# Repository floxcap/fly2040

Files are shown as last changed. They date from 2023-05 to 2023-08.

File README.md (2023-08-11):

# fly2040

RP2040 board, leds, firmware and homebrew designed to be picofly compatable.

NOTE: Using `git-subrepo` for submodules. See [git-subrepo](https://github.com/ingydotnet/git-subrepo) for usage.

## Credits
- Further credits in relevant sub-folders.
- A huge thank you to [SciresM](https://github.com/SciresM) for all of the guidance and help in getting this working.
- Also a huge thank you to [CTCaer](https://github.com/CTCaer) for all of the guidance and focus on the small details.
- Thanks to [rehius](https://github.com/rehius) for the picofly firmware which was the foundation for the fly2040 firmware.
- Thanks to [lightninjay](https://gbatemp.net/members/lightninjay.643395/) for his guide [guide](doc/PicoFlyGuideV.6.2-1.pdf) and [guide-thread](https://gbatemp.net/download/a-definitive-picofly-install-guide.37968/).

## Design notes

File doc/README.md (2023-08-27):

# fly2040

RP2040 board is intended to be connected to I2C port #1.

The V1_V2 image shows the points I used for my mod.
The Lite image shows the likely points for a Lite board - but has not yet been confirmed or tested.

You may be able to trace the board layers/i2c points using: [Board Layers](https://balika011.hu/switch/)

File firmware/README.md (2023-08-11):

# fly2040 firmware

Firmware derrived from picofly firmware.

Added i2c slave mode for WS2812 led strip control from homebrew.

For i2c to work with the sysmodule as it it will need to be connected to i2c bus #1.

(Images to be inserted here)

## Credits
- Thanks to [rehius](https://github.com/rehius) for [usk](https://github.com/rehius/usk)
- Thanks to [vmilea](https://github.com/vmilea) for [pico_i2c_slave](https://github.com/vmilea/pico_i2c_slave)

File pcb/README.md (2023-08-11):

# fly2040 pcbs
KiCad designs for a RP2040 board and supporting boards.

Note - The main board requires a 3.3V power supply when programming.<br>
The intention is to be able to program the boards with a 1.27mm pitch test clip / pogo pins.
(See: [usb_programmer](usb_programmer)).

The [fly2040_rgb](fly2040_rgb) board is the main board and has been tested and working
on V1/V2/Lite devices.

The [fly2040_leds](fly2040_leds) adds support for a flex led strip.

The [cpu_flex](cpu_flex) is untested.

## Installation
See: [guide](../doc/PicoFlyGuideV.6.2-1.pdf) or [guide-thread](https://gbatemp.net/download/a-definitive-picofly-install-guide.37968/)

The usb-programmer board is designed to accept the P50-E2 (shaft diameter 0.68mm) which should be soldered in
to the (programmer) board.
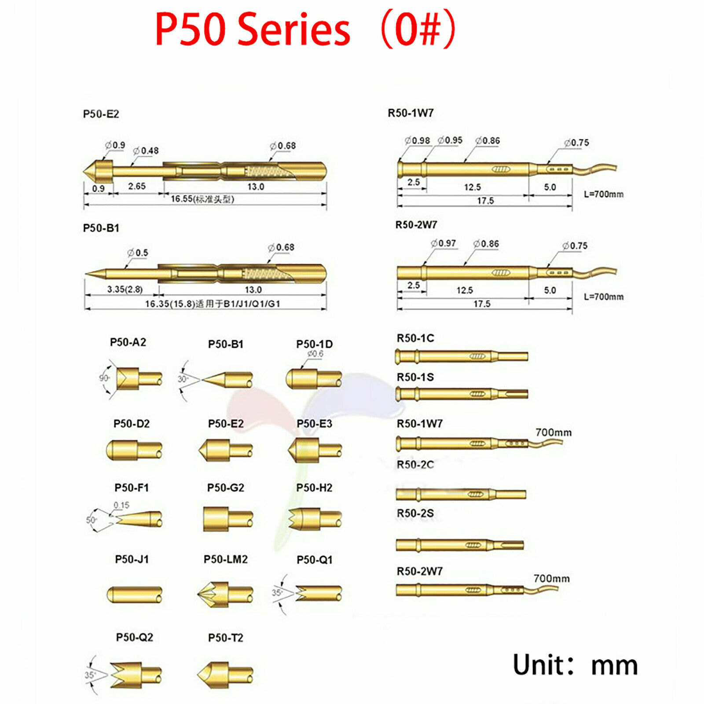
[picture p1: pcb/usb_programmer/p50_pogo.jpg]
Pogo pins


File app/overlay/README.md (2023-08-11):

# sys-rgb overlay

overlay is not currently developed.
TBD / TODO.

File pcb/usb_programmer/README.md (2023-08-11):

# fly2040 USB Programmer
KiCad design for a basic programmer board.

Note - This design is currently untested.

The usb-programmer board is designed to accept the P50-E2 (shaft diameter 0.68mm) which should be soldered in
to the (programmer) board.<br><br>


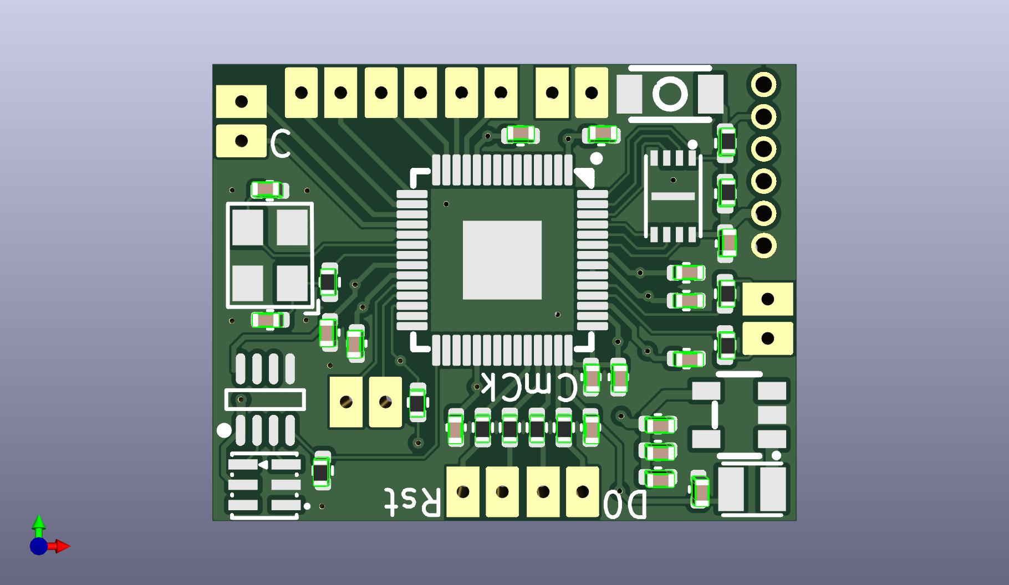
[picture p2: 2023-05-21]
images/fly2040_front.jpg

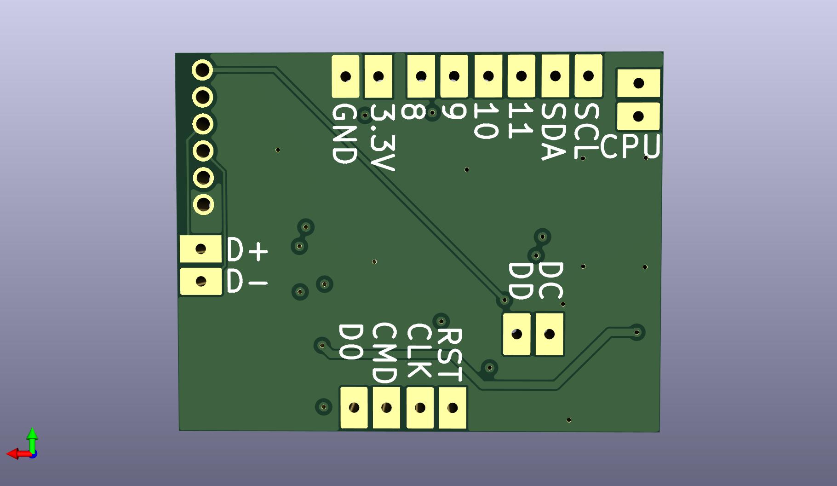
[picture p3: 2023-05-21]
images/fly2040_back.jpg

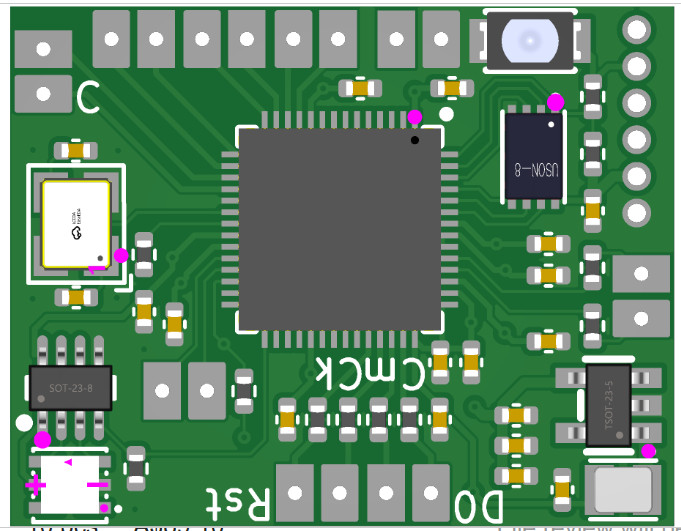
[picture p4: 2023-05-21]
images/jlcpcb.jpg

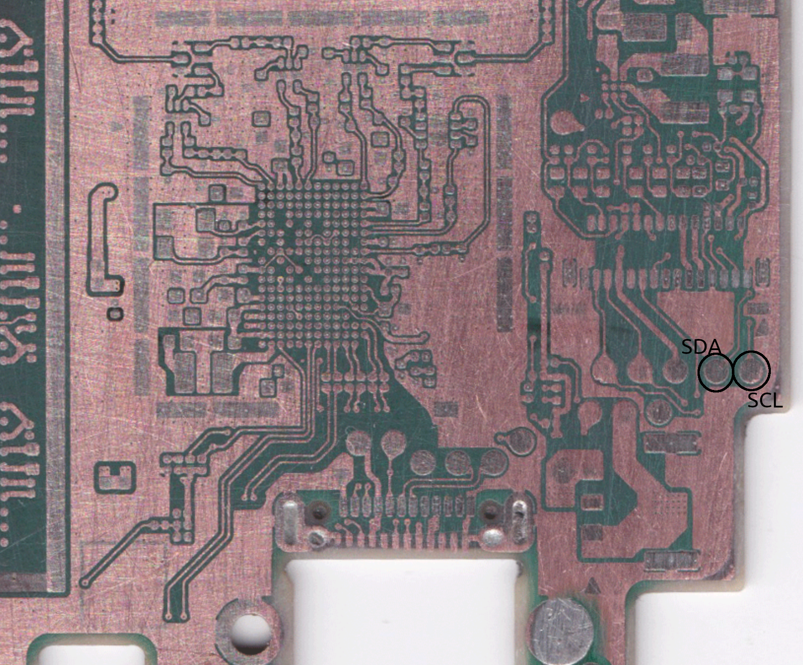
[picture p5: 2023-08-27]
doc/Lite_i2c_1_unconfirmed.png

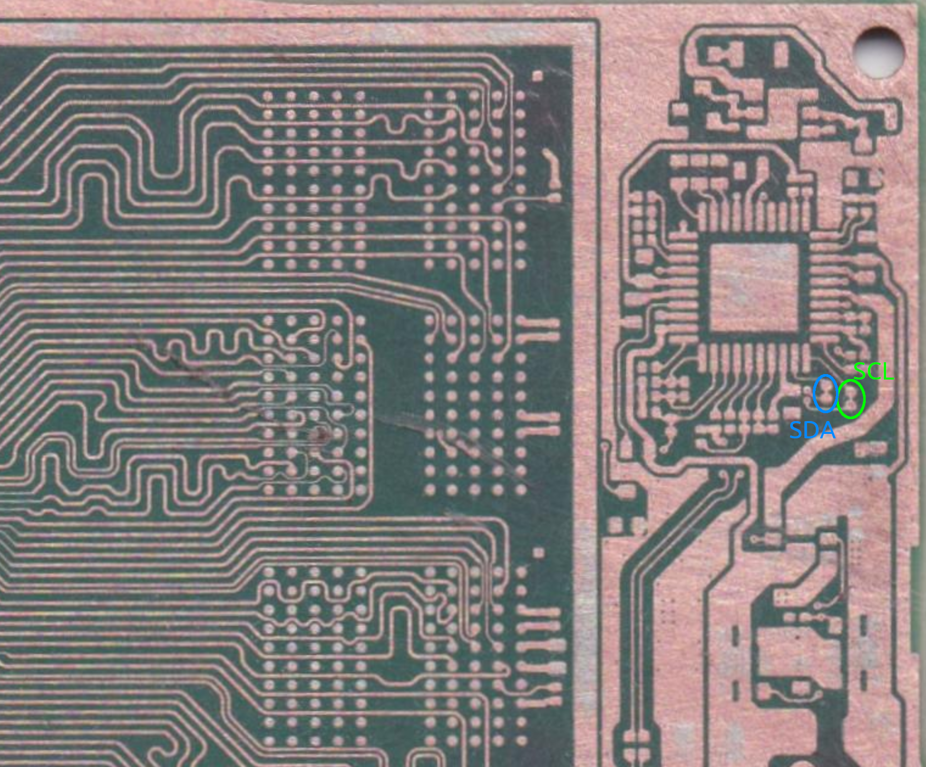
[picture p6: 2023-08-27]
doc/V1V2_i2c_1.png

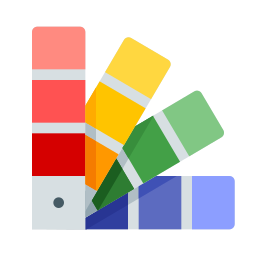
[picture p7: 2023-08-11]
app/manager/resources/img/sys-rgb.png

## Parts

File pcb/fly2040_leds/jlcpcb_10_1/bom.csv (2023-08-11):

Comment | Designator | Footprint | LCSC
XL-1010RGBC-WS2812B | U1,U2,U3,U4,U5,U6,U7,U8,U9 | kicad_lceda:LED-SMD_4P-L1.0-W1.0-TL_XL-1010RGBC-WS2812B | C5349953

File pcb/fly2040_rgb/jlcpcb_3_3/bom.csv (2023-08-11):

Comment | Designator | Footprint | LCSC
47 | R9,R10,R11 | R_0402_1005Metric | C25118
100nF,16V,X7R | C2,C4,C7,C8,C9,C10,C11,C12,C13,C14 | C_0402_1005Metric | C1525
10k | R2,R3,R4,R6,R7,R12 | R_0402_1005Metric | C25744
RP2040 | U1 | kicad_lceda:LQFN-56_L7.0-W7.0-P0.4-EP | C2040
1k | R1,R5 | R_0402_1005Metric | C11702
EVPAWED40 | SW1 | kicad_lceda:KEY-SMD_L3.0-W2.0-LS3.5 | C2858607
W25Q16JVUXIQ | U2 | kicad_lceda:USON-8_L3.0-W2.0-P0.50-BL-EP | C2843335
XL-1010RGBC-WS2812B | U5 | kicad_lceda:LED-SMD_4P-L1.0-W1.0-TL_XL-1010RGBC-WS2812B | C5349953
27pF,50V,C0G | C1,C3 | C_0402_1005Metric | C1557
SMD-3225_4P_12.000MHZ_9PF | X1 | kicad_lceda:OSC-SMD_4P-L3.2-W2.5-BL | C362368
1uF,25V,X5R | C5,C6 | C_0402_1005Metric | C52923

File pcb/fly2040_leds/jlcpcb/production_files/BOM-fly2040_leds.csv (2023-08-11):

Comment | Designator | Footprint | LCSC
XL-1010RGBC-WS2812B | U1,U2,U3,U4,U5,U6,U7,U8,U9 | LED-SMD_4P-L1.0-W1.0-TL_XL-1010RGBC-WS2812B | C5349953

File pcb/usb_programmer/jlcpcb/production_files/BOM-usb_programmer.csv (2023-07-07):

Comment | Designator | Footprint | LCSC
TYPE-C-31-M-12 | J1 | USB_TYPE-C | C165948
10k | R1 | R_0402_1005Metric | C25744
5.1k | R2,R3 | R_0402_1005Metric | C25905
KMR221GLFS | SW1,SW3 | KEY-SMD_KMR2XXGXXX | C72443
RT9080-33GJ5 | U1 | TSOT-23-5_L2.9-W1.6-P0.95-LS2.8-BL | C841192

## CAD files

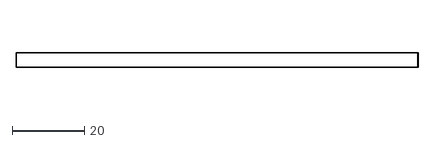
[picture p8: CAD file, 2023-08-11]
pcb/fly2040_leds/Gerber/fly2040_leds-User_Comments.dxf
111.2 x 4.05

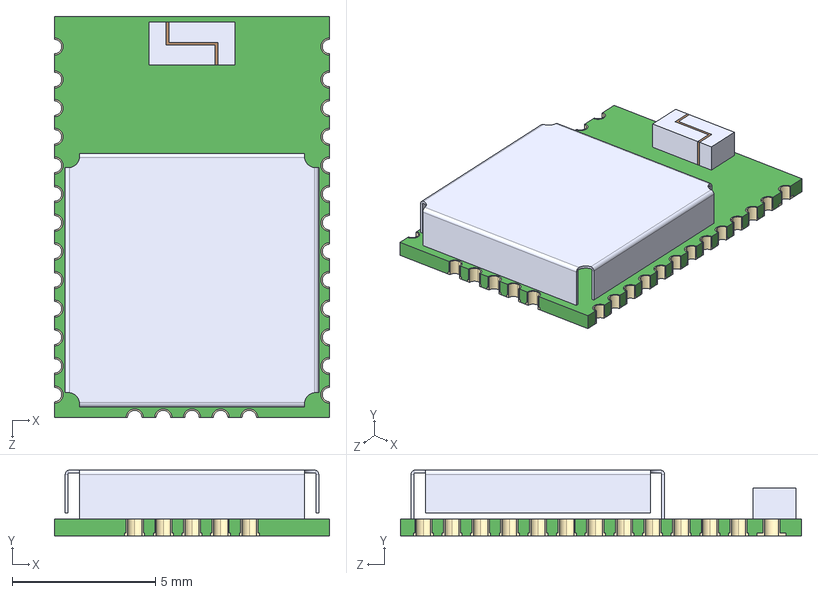
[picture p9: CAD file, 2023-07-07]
pcb/usb_programmer/3DSteps/CAM-M8Q-0.step
9.60 x 2.30 x 14.0 mm

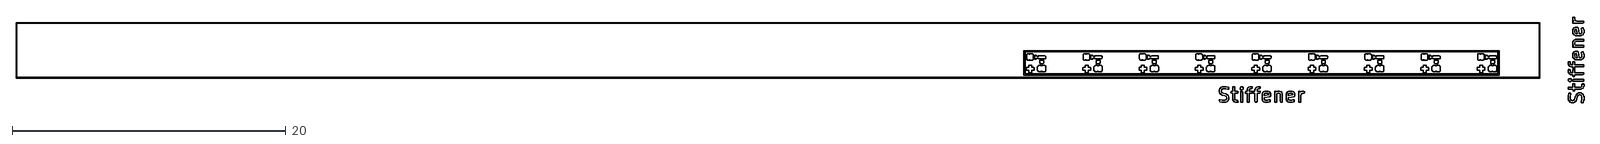
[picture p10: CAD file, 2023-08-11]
pcb/fly2040_leds/Gerber/fly2040_leds-User_Drawings.dxf
114.5 x 6.24

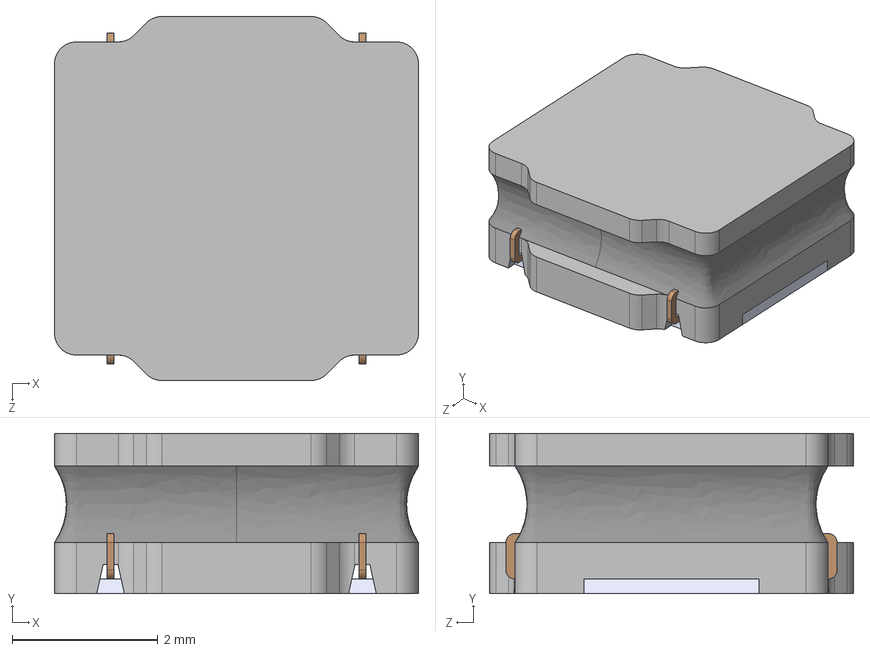
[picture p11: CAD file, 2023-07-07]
pcb/usb_programmer/3DSteps/IND_LQH5BPN4R7NT0L.step
5.00 x 2.20 x 5.00 mm

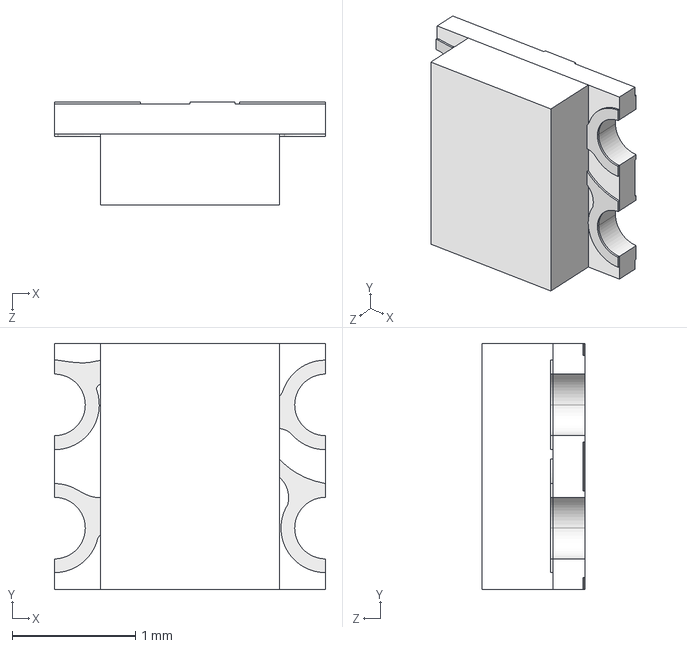
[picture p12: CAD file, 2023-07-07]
pcb/usb_programmer/3DSteps/WS2812-2020.step
2.20 x 2.00 x 0.84 mm

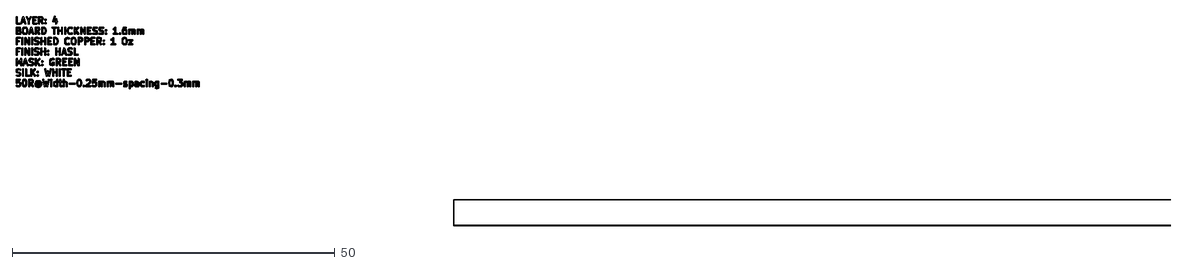
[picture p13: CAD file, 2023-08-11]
pcb/fly2040_leds/Gerber/fly2040_leds-Margin.dxf
179.1 x 32.5

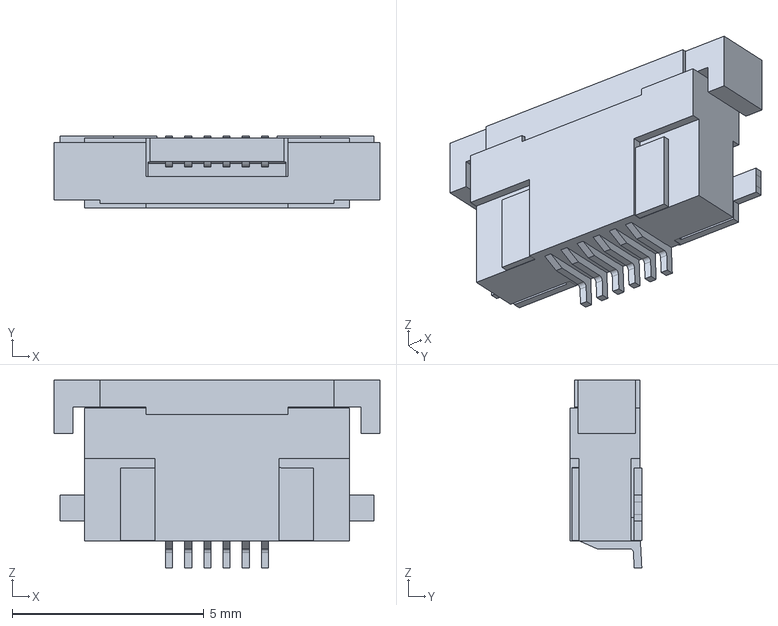
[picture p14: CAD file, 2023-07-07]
pcb/usb_programmer/3DSteps/FPC_6PIN_sfv6r3ste1hlf.stp
8.50 x 1.87 x 4.90 mm

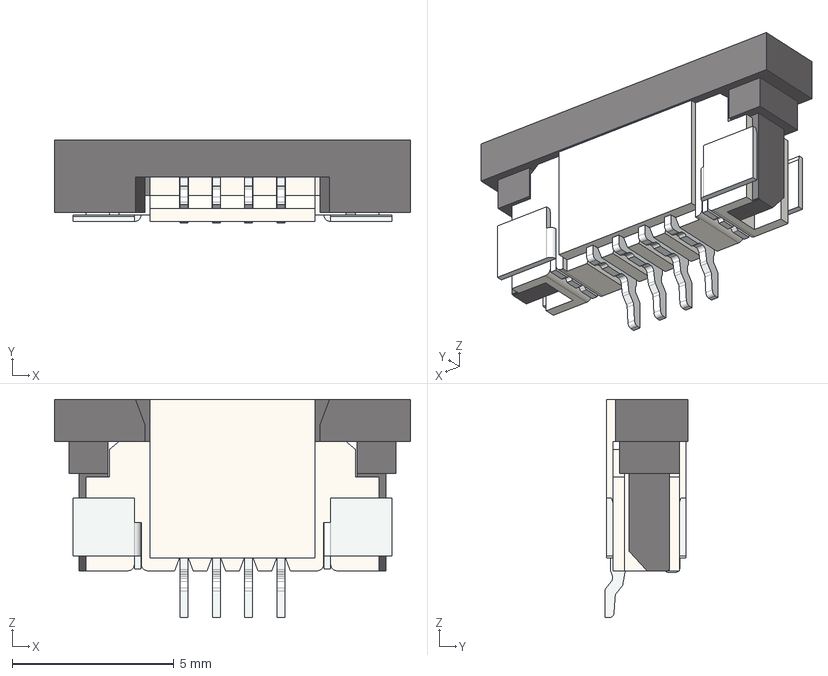
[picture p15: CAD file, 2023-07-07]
pcb/usb_programmer/3DSteps/FFC3B07-04-T.stp
11.0 x 2.57 x 6.75 mm
_FFC3B07-04_H1
_FFC3B07-04_H2
_FFC3B07_SC x 2
_FFC3B07-T_P x 4

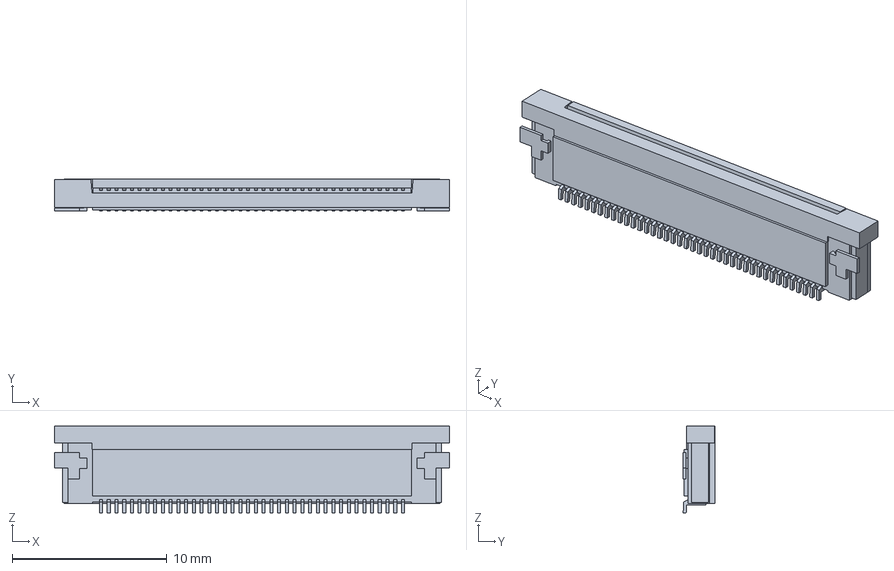
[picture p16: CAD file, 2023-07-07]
pcb/usb_programmer/3DSteps/TFT_62684402100alf.stp
25.5 x 2.05 x 5.60 mm

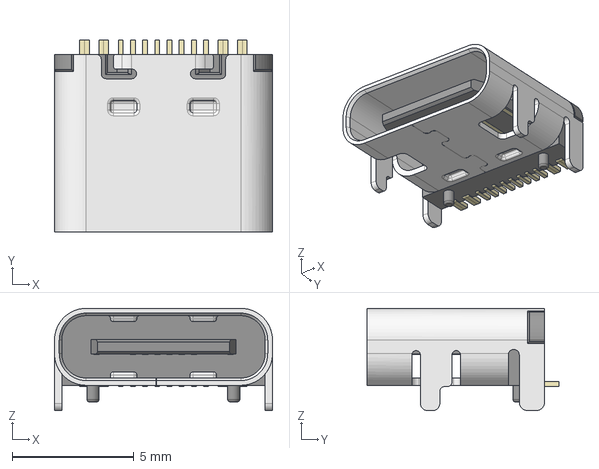
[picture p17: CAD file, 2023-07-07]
pcb/usb_programmer/3DSteps/HRO_TYPE-C-31-M-12.step
8.95 x 7.90 x 4.20 mm

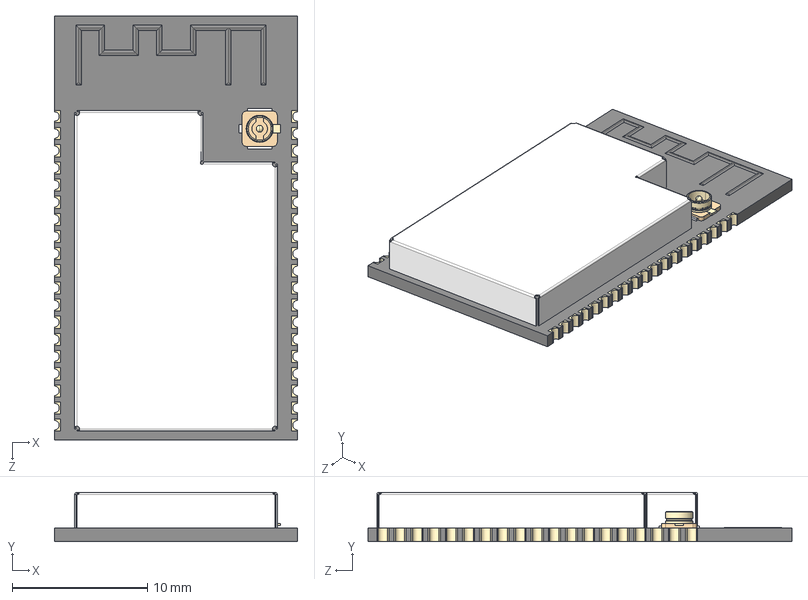
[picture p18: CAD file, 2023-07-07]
pcb/usb_programmer/3DSteps/ESP32-WROVER-E.step
18.0 x 3.65 x 31.4 mm

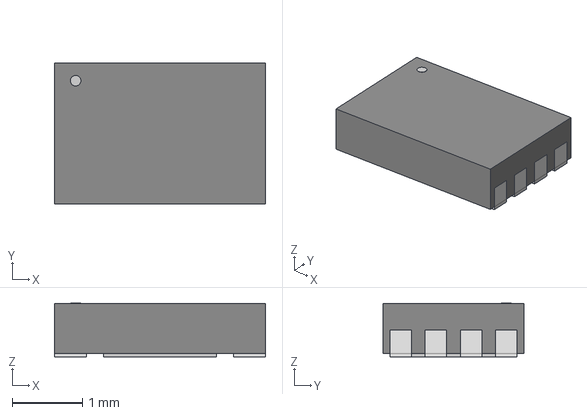
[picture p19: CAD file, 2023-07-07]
pcb/usb_programmer/3DSteps/TDFN8_2x3MC_MCH.step
3.00 x 2.01 x 0.765 mm

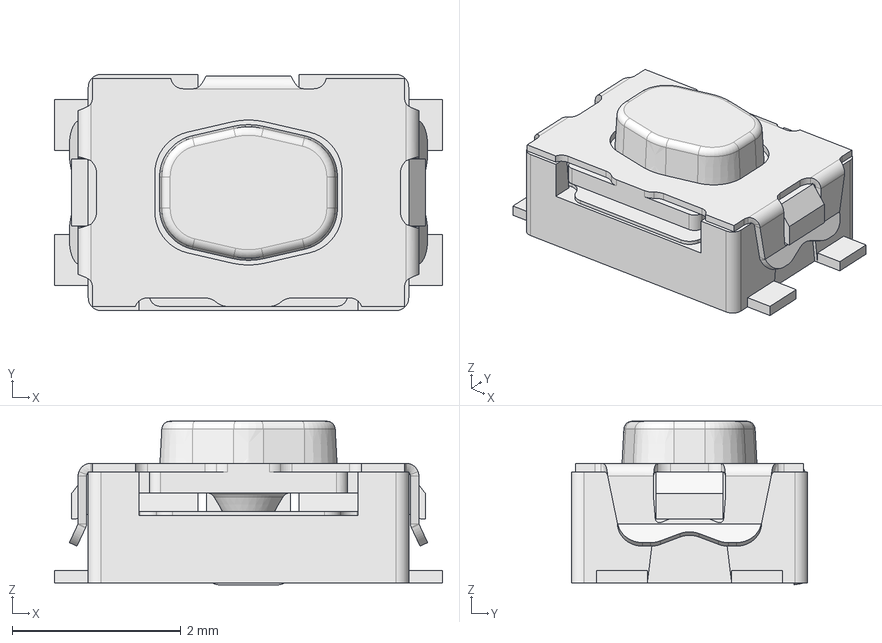
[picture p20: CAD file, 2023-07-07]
pcb/usb_programmer/3DSteps/KMR211GLFS.step
4.60 x 2.80 x 1.94 mm

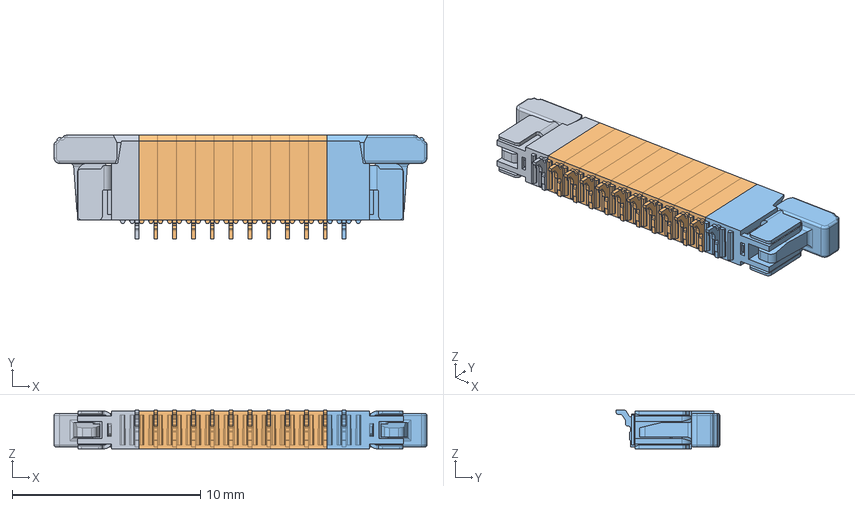
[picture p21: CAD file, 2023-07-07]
pcb/usb_programmer/3DSteps/F52R-1A7H1-11012.stp
19.8 x 5.50 x 2.05 mm
F52R_L
F52R_M x 10
F52R_R

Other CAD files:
pcb/usb_programmer/3DSteps/2-84952-4.step
pcb/usb_programmer/3DSteps/S2B-PH-SM4-TB(LF)(SN)--3DModel-STEP-56544.STEP
pcb/usb_programmer/3DSteps/KMR621NG LFS.step
pcb/usb_programmer/3DSteps/436333045822_Download_STP_436333045822_rev1.stp
pcb/usb_programmer/3DSteps/528080470.stp
pcb/usb_programmer/3DSteps/WLCSP6_1P48X0P98_ONS.step

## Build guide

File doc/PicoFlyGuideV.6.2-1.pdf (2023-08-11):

Flashing your PicoFly, An Overview
At the heart of all the dev boards is an SoC (System on a Chip) known as the RP2040. It has its own built-in firmware flashing system that involves it presenting itself to your computer as a USB drive.
If it has never been programmed before, simply plugging it into your computer should bring up a window with two files in it. This is the firmware flashing window. If you drag and drop a ".uf2" file into this window, the RP2040 will read the file and attempt to flash it. This will cause the window to close, and the next time you plug the RP2040 in, it will not present itself as a USB drive to your PC.
To reprogram an already-programmed RP2040, there is typically a "boot" button that needs to be held down while being plugged into USB, but when you do this and the window shows up, your firmware file will not be displayed in the window since it IS NOT a storage device. The RP2040 just tricks your computer into treating it like a storage device. Some recommend that between flashes you use a "flash_nuke.uf2" provided by the Raspberry Pi Foundation. This basically just flashes all zeroes to the RP2040 firmware memory to ensure a clean flash of whatever you put on it next.

We want to flash our device with Rehius' most up-to-date PicoFly firmware, which can be located at GBAtemp:

https://gbatemp.net/threads/picofly-a-hwfly-switch-modchip.622701/page-78#post-10090767

As of the current date (4-06-2023), "fw_2.74.uf2" is what needs to be flashed to your dev board. Remove the .pdf from the end of the file before flashing.

With this file downloaded, and your RP2040-Zero plugged into your PC, showing the firmware flashing window, keep one eye on the LED of your RP2040-Zero. As you drop the .uf2 file into the window, your LED should flash as the window on your PC closes. This is to indicate firmware flashing success, but the color of this LED is what we are concerned with now.

If the LED flashes Yellow once, GREAT, you don't need to do anything special, however, if you get multiple flashes, or no flash at all, the flash was unsuccessful and you need to attempt flashing the firmware once again.

You can hold the boot button, plug your RP2040-Zero back into your computer, flash the .uf2 to the board again and look for a Yellow LED flash now.

At this point, with a firmware loaded on the board, we can start to prep it to go into the switch.

Conventionally, folks remove the USB-C port and the boot + reset buttons. Below is an example of a finished install with USB-C removed, buttons removed, resistors installed, and as you may notice, a mix of 30awg Kynar (for power supply to RP2040-Zero) and about 36awg magnet wire for the remaining wires.

During this step of removing ports, it is also recommended to add the three resistors to the side of your board. With the boot button removed, some people place their resistors to the inside of the board, rather than hanging from the edge. Both will functionally work.

If you have slow EMMC issues after putting everything together, one possible reason is that you need two additional resistors, one each on CMD and DAT0, like below, for a total of 94 ohms on each line:

There could be other reasons for slow EMMC as well though, like residual flux on solder points, or wires being too thin or too long on CLK, CMD, or DAT0.

On that same note, if you leave flux residue on RST points, your console could instantly reboot after startup, as the RST points are very sensitive.

Time to open up your console and get to work!

# Preparing your PicoFly

1) Nintendo Switch (V1, V2, Lite, or OLED) ANY model
2) Soldering station
- Soldering iron that is preferably digitally controlled so you know what temp you solder at
- Solder (some recommend low-temp leaded fluxless solder to make some parts slightly easier)
- Flux (this is NOT optional. When soldering at these scales, flux is absolutely vital to making good solder joints) Applied with the tip of a wooden toothpick is how I usually hit small spots
- A damp sponge and/or brass wire sponge to keep your soldering tip clean. I use both.
- The tip you use can be vital depending on the locations of your soldering points. I use a ts-100 iron and swap between three different tips:
TS100-JL02 | TS-BC2

TS-I

3) A tweezer kit
I know this sounds ridiculous, but trust me. Handling components this small REQUIRES fine-point tweezers. You may be able to SEE the components without a magnifier or scope, but you won't be able to manipulate and solder things like 0805 (or even smaller) resistors with bare fingers.

I ordered this kit off of Amazon https://www.amazon.com/gp/product/B07S1DMKDX/

4) Wire
This would seem like a no-brainer, but the type of wire you use can ultimately make or break your install. I used a mix of 30awg Kynar and 40awg magnet wire. I have seen installs with all 30awg, and installs with all 40awg. Your luck may vary, but smaller wire tends to be a little more forgiving on small components when soldering.
5) 47ohm to 50ohm 0805 Resistors These resistors are soldered onto DAT0, CLK, and CMD on the PicoFly, then wires are soldered from the switch motherboard to the resistors. There are two types you can generally get away with using: 470 and 47R0 The 470 typing are 47 ohms +/-5% whereas 47R0 are 47 ohms +/-1%
Other sizes than 0805 will work, but 0805 seem to be easier to fit on the soldering pads of the RP2040-Zero
6) Mosfet(s) or an HWFLY flex cable appropriate to your specific console.
-If using mosfets by themselves, it is recommended that you purchase model IRFHS8342 due to its size and its ability to fit in place under the APU shield

-If using a flex cable (which has integrated mosfets) then order a V1 cable for Erista models, or a V2 cable for Mariko, Lite, or OLED models (You can also use V3 OLED cables, it's a choice of where the flex cable comes out of the APU shield).

Erista | Mariko/Lite/OLED
7) A magnifier of some kind
There are plenty of folks (myself included) that can get away with using a cellphone camera to zoom in and make sure joints aren't bridged and that good solder contact is being made. Others will say you absolutely need a scope to do this job so that you can see all the small components on a well-lit screen while working. It's up to what you're most comfortable with.
8) Kapton Tape
This seems to get overlooked in some cases, but the kapton tape helps to electrically isolate the picofly from accidentally shorting anything once it's installed and closed up.
9) Thermal Paste
Another oft-overlooked item to improve your switch's lifespan after this mod. Good thermal paste being properly applied after cleaning all the old stuff off is vital to not overheating your console which leads to console shutoff into standby mode.

Last but not least
10) An RP2040 dev board
This is partially where the community starts to get divided, beyond what kind of switch you are modding.
A vast majority of the community has been using RP2040-Zero boards from Waveshare/Aliexpress, but thanks to Rehius, the firmware dev, several types of dev board are currently supported. I will attempt to list some of the most popularly used ones thus far. For this guide, I am focusing on The RP2040-Zero
~ RP2040-Zero ~ RP2040-One ~ RP2040-Tiny

~ Seeed XIAO-RP2040 ~ Adafruit ItsyBitsy RP2040

See the end of the guide for diagrams of how to wire up the Seeed or the Adafruit

Optional, but recommended
11) UV-cure solder mask
-It cannot be overstated how small these components are. Once your wires are faithfully
in place, many would recommend a small amount of solder mask be applied to hold things in place,
as well as help insulate connections from shorting
12) Digital Multimeter
-Use this to check your wiring when you are done. It can be used to detect shorts to ground, or in diode mode to detect proper connections. If you don't understand any of that, THIS MOD IS NOT FOR YOU, HAVE A PROFESSIONAL INSTALL IT FOR YOU.

Recommended materials

Here there be DRAGONS! DOING THIS MODIFICATION TO YOUR SWITCH MAY CAUSE PERMANENT DAMAGE. I RECOMMEND YOU HAVE THIS DONE BY A PROFESSIONAL INSTALLER.

"Just because a mod is cheap doesn't mean it's easy. -Trust me I learnt the hard way" - Adran (GBATEMP 2023)

SERIOUSLY, if you've NEVER soldered before, this is not the mod for you to attempt yourself. The photos that you've seen to make you so confident you can do this yourself? They're usually in the ballpark of 10-20 times zoom. Most of the things you are seeing on this scale are millimeter or smaller in measurement. This mod requires good lighting, steady hands, all the right equipment, and most of all, experience with soldering. Knowledge of why flux works, and why it is so important to be used in small projects like this cannot be overstated. Please, don't kill your switch, this isn't r/techgore, we don't want to see photos of your ripped traces and your tears stained on the motherboard...

Disclaimer: this guide is written using many different sources of information. It is not my work, I am merely combining it here in this PDF to make it more accessible to the general public. I take no responsibility for anything that may happen to your device, good or otherwise. This guide is provided as-is, and you are responsible for anything that may happen.

This guide will go over the basics of PicoFly setup, and wants to reiterate, this hardware mod can be installed on ANY switch (including unpatched V1's) running ANY firmware. It is CPU-glitch based, which loads a payload before Nintendo-signed software bootloader.

V.6.2

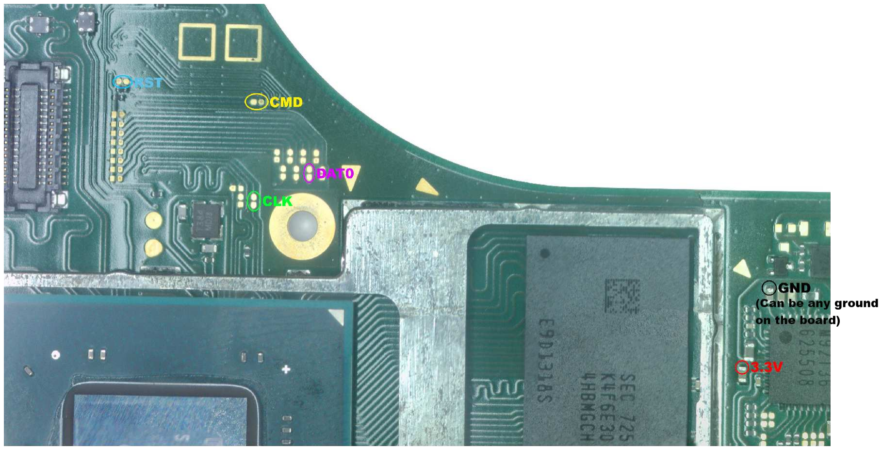
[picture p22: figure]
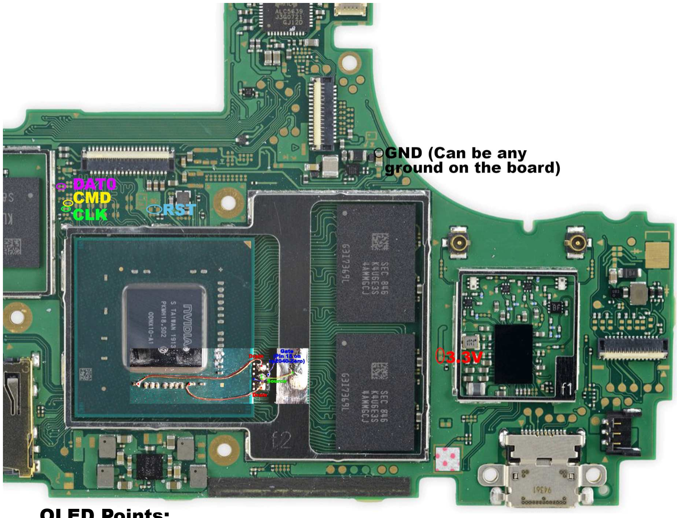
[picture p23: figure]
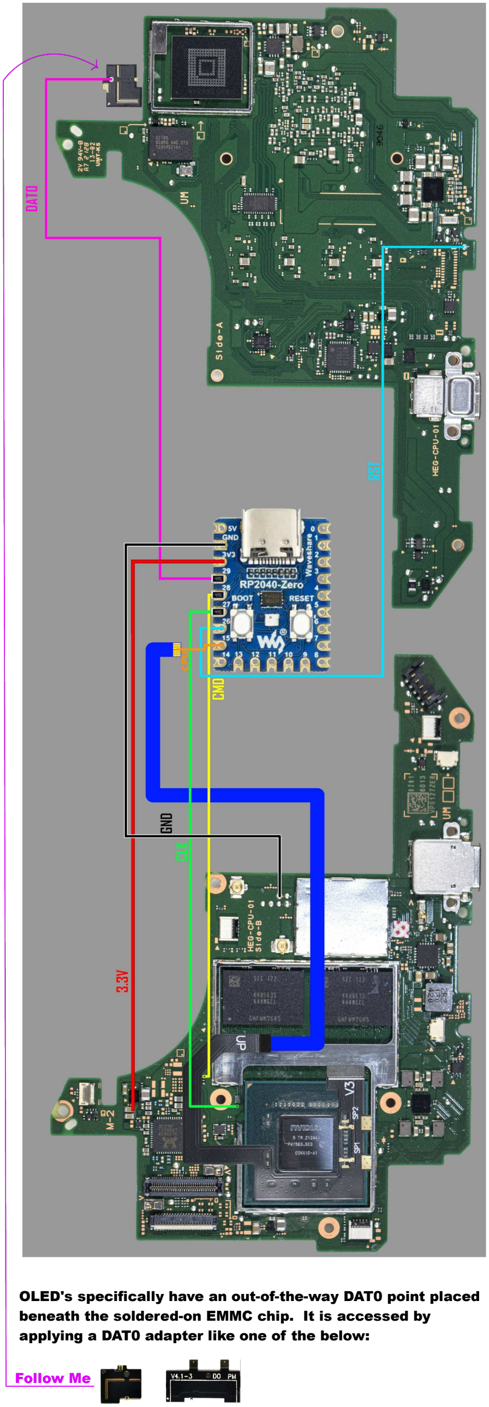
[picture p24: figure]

Bear in mind, I recreated these images in photo editing software, but this is what is currently displayed on my switch. I have flashed several updates, so my fuse count is greater than 0, and I am currently on v2.64

Updating
To actually use the tool to update your picofly from V2.6+ to something higher, simply place the desired firmware's ".bin" update in the root of your SD card and name it "update.bin". Launch PicoFly Toolbox, then scroll down once to "Update" by hitting "Vol -" one time, then hit the power button once. The toolbox will now look for the "update.bin" where it is supposed to be, and will flash the firmware provided inside the file. You will be asked to reboot, and may experience slightly longer boot times for the first few boots after updating. This is normal, once the PicoFly re-trains, you will be back to fast boots.

Rolling Back
PicoFly stores the last firmware you flashed from, in the event of a failed flash, it can auto-rollback to whatever version you were flashing from. If in the event you have a successful flash to a higher version, but wish to intentionally rollback to your previously running version, from the main menu of PicoFly Toolbox, scroll down twice with the Vol - button being pressed twice, then select Rollback with the power button. Similar to an update, you will be asked to reboot.

SD Loader
To my understanding, SD Loader is the portion of Boot0 which is being modified to load unsigned SD payloads (such as our custom bootloader of choice, typically Hekate). The "No SD Card" screen is part of this SD Loader portion. To make a backup or restore this portion, just use the two options seen in their respective portion of the menu, but you really shouldn't have to mess with this unless directed to do so.

Training Data Reset
As the name might imply, this is to reset the training data of the PicoFly in the event your boot times have gone awry for some reason. This will clear your training data and allow your PicoFly to attempt relearning new glitch timings for your console. Largely this should be unnecessary, but it is here if needed.

This guide has been brought to you by Lightninjay, a member of the GBATEMP forums, and in no way implicates them for any harm that may come to you or your devices while following this guide.

As a courtesy, here are some pinouts of alternate boards that PicoFly should be compatible with, thanks to forum member, Dee87, colors added by myself

SEEED XIAO-RP2040

Adafruit ItsyBitsy RP2040

Raspberry Pi Pico

There are plenty of guides on Youtube on how to properly open your console, so I will merely reference those below:

V1 and V2 disassembly:
https://www.youtube.com/watch?v=QCZ3-fYjpWo

Lite disassembly:
https://www.youtube.com/watch?v=GP1DHRs6V2Y

OLED disassembly:
https://youtu.be/4umniX8nX5E?t=40s

Once you're inside, you'll need to reference the following photos to solder your wires into the console:

Please Be Advised:
You may see two pads inside one circle in the below photos. THIS IS INTENTIONAL. This means that both pads are part of the same trace. That means you can solder to either pad, or both, whichever suits the size of wire you are using.

If using a flex cable, the CPU pin on your RP2040 needs to be connected to the two middle pins of the flex cable (pins

### 3 and 4). Do not bridge to pins 2 or 5 accidentally, this will

likely cause an error light on your RP2040. Use Kapton tape as seen below to make soldering the two pins easier:

V1/V2 Points:

Lite Points:

OLED Points:

OLED's specifically have an out-of-the-way DAT0 point placed beneath the soldered-on EMMC chip. It is accessed by applying a DAT0 adapter like one of the below:

Use this link to watch sthetix place his adapter and wire it up: https://youtu.be/y5-TPVecVsw?t=415

The last part is the installation of mosfets or of the HWFLY cable. Functionally the install is the same for all models, the main difference is orientation of the vertical APU capacitors from the V1 model to the other 3 models that place the capacitors horizontally. Here is a section of a video with one of these cables being installed:

https://youtu.be/XG80TcbO5Uo?t=107

If you do not have access to a cable and are doing a bare mosfet install, here are some photos to reference
of the clever ways people have been wiring theirs up:
- V1 Erista (vertical capacitors)

-V2 Mariko, Lite, OLED

If it isn't so clear, here are a few photos of some mosfet installs:

This is a single mosfet install, where the left capacitor of this V2 board has been removed, so the wire is just hitting the right-side pad of the left cap:

And here is a slightly more complex, but well-executed, install of double mosfets that have been secured with solder-mask:

Also importantly, if you are to accidentally remove one or more of these capacitors, you may be fine, but to replace them, you can rob a few off of a RP2040-Zero, without affecting the function of the PicoFly. These 100nF caps are located here:

Once you have your mosfet(s) installed, make sure all your new points are electrically insulated from the APU shield as you put it back on.

Now simply solder all of your flying wire leads to their appropriate points on your RP2040.

Before attempting to boot, make sure you did not accidentally bridge any extra contacts, as this could ruin your console.

Once you're ready, push the power button on your console after plugging the battery back in. The PicoFly should flash blue, (on first boot, it should flash white after blue) then yellow to indicate success! Should you see this order of lights, try flipping your console over carefully and checking the screen to see this

If you're met with this screen, then that is as far as this guide takes you, as you have successfully modded your switch with PicoFly, congratulations! At this point you can follow any number of HATS pack guides to prepare an SD card for your device, but the gist is that it is looking for a "payload.bin" located in the root of the SD card. As long as all the supporting files for that payload.bin have been copied to the SD card along with it, then everything should boot fine.

On the other hand, if you didn't see Blue, White (SDloader Mem write), then Yellow on your LED, and your console either boots to a black screen, or instead boots to OFW like normal, then look at the following LED code list to diagnose your potential issue:
= is long Yellow pulse, * is short Yellow pulse:

= USB flashing done, * Successful glitch

** RST is not connected
*= CMD is not connected
=* D0 is not connected
== CLK is not connected

*** No eMMC CMD1 responce (bad eMMC?)
**= No eMMC block 1 read (should not happen)
*=* No eMMC block 0 read (eMMC init failure?)
*== No eMMC CMD1 request (poor wiring, or dead CPU)

=** eMMC init failure during glitch process
=*= CPU never reach BCT check, should not happen
==* CPU always reach BCT check (no glitch reaction, check mosfet)
=== Glitch attempt limit reached, cannot glitch

=*** eMMC init failure
=**= eMMC write failure - comparison failed =*=* eMMC write failure - write failed
=*== eMMC test failure - read failed
==** eMMC read failed during firmware update ==*= BCT copy failed - write failure
===* BCT copy failed - comparison failure
==== BCT copy failed - read failure

Hopefully at this point you have managed to hack your console, and are looking forward to the following hours of configuring and tweaking your setup! If not, and you're still having glitch issues and are on firmware 2.70 or higher, you can try installing two additional i2c wires for a low-voltage glitch:
From Rehius:
If your glitch is unstable (==* error), and
the proper boot happens only when you press Reset after joycon logo, you can add two more wires to make glitch much better.
board pins:
Waveshare rp2040: SDA=12, SCL=13
Pi Pico: SDA = 19, SCL = 20
XIAO 2040: SDA=3, SCL=4
ItsyBitsy 2040: SDA = 18, SCL = 19
V1/V2 | Lite

OLED

## PicoFly Toolbox

"picofly_toolbox_0.2.bin" (available from Rehius' post where the firmware is downloaded from) is the current payload that you can load through Hekate's payload launcher, to interface with your PicoFly. The caveat to this, is that you must be on at least firmware v2.6 to use the toolbox as a feature. This means, if you have previously loaded your PicoFly with an out-of-date firmware, like the frequently circulated "2.5 toshiba + unlock", you must flash at least 2.6 to your PicoFly via USB and a computer before you can interact with PicoFly using the toolbox.
Once you are on minimum v2.6, you can launch the toolbox to its main menu, which looks like this:

You can use Vol +/- to navigate up and down the menu, and then press the power button to select a menu option. If you hit power on the info option, you will be presented with a screen similar to the one below:

# UNPLUG YOUR BATTERY ONCE THE CONSOLE IS OPEN, BEFORE TOUCHING ANYTHING ELSE!

# Modding your console

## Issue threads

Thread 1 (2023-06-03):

Gerbers?

Kinokoda, 2023-06-03:
Are you going to compile Gerber files for JLCPCB, or will you just have the PCB files available? Both are perfect.

floxcap, 2023-06-05:
Yes - there are files there for JLC (gerbers & bom & cpl).
Best example is in: pcb/fly2040_min/jlcpcb/production_files
(I sent this to JLC just recently)

Closed 2023-06-05.

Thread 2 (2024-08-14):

Crashing in sys-rgb-manager on 18.0.0

vulpvibes, 2024-08-14:
Hello, I recently wanted to test this firmware with the [Home Button LED mod](https://gbatemp.net/threads/picofly-a-hwfly-switch-modchip.622701/page-542#post-10192490) I made over on GBAtemp, but I am unable to run sys-rgb-manager without crashing, either in applet mode or full app mode. Applet mode crashes Atmosphere entirely with error code 2168-0002 (0x4a8) and Program: 010000000000100D, and full app mode more gracefully closes with a game error message and returns to home menu. I am using a normal RP2040-Zero, and my wiring seems correct for all points, SDA and SCL included. The SD card has been set up with a fresh install of the latest Hekate and Atmosphere, with no other add-ons. Any assistance with this issue or guidance on modifications that may need to be made for the RP2040-Zero are greatly appreciated.

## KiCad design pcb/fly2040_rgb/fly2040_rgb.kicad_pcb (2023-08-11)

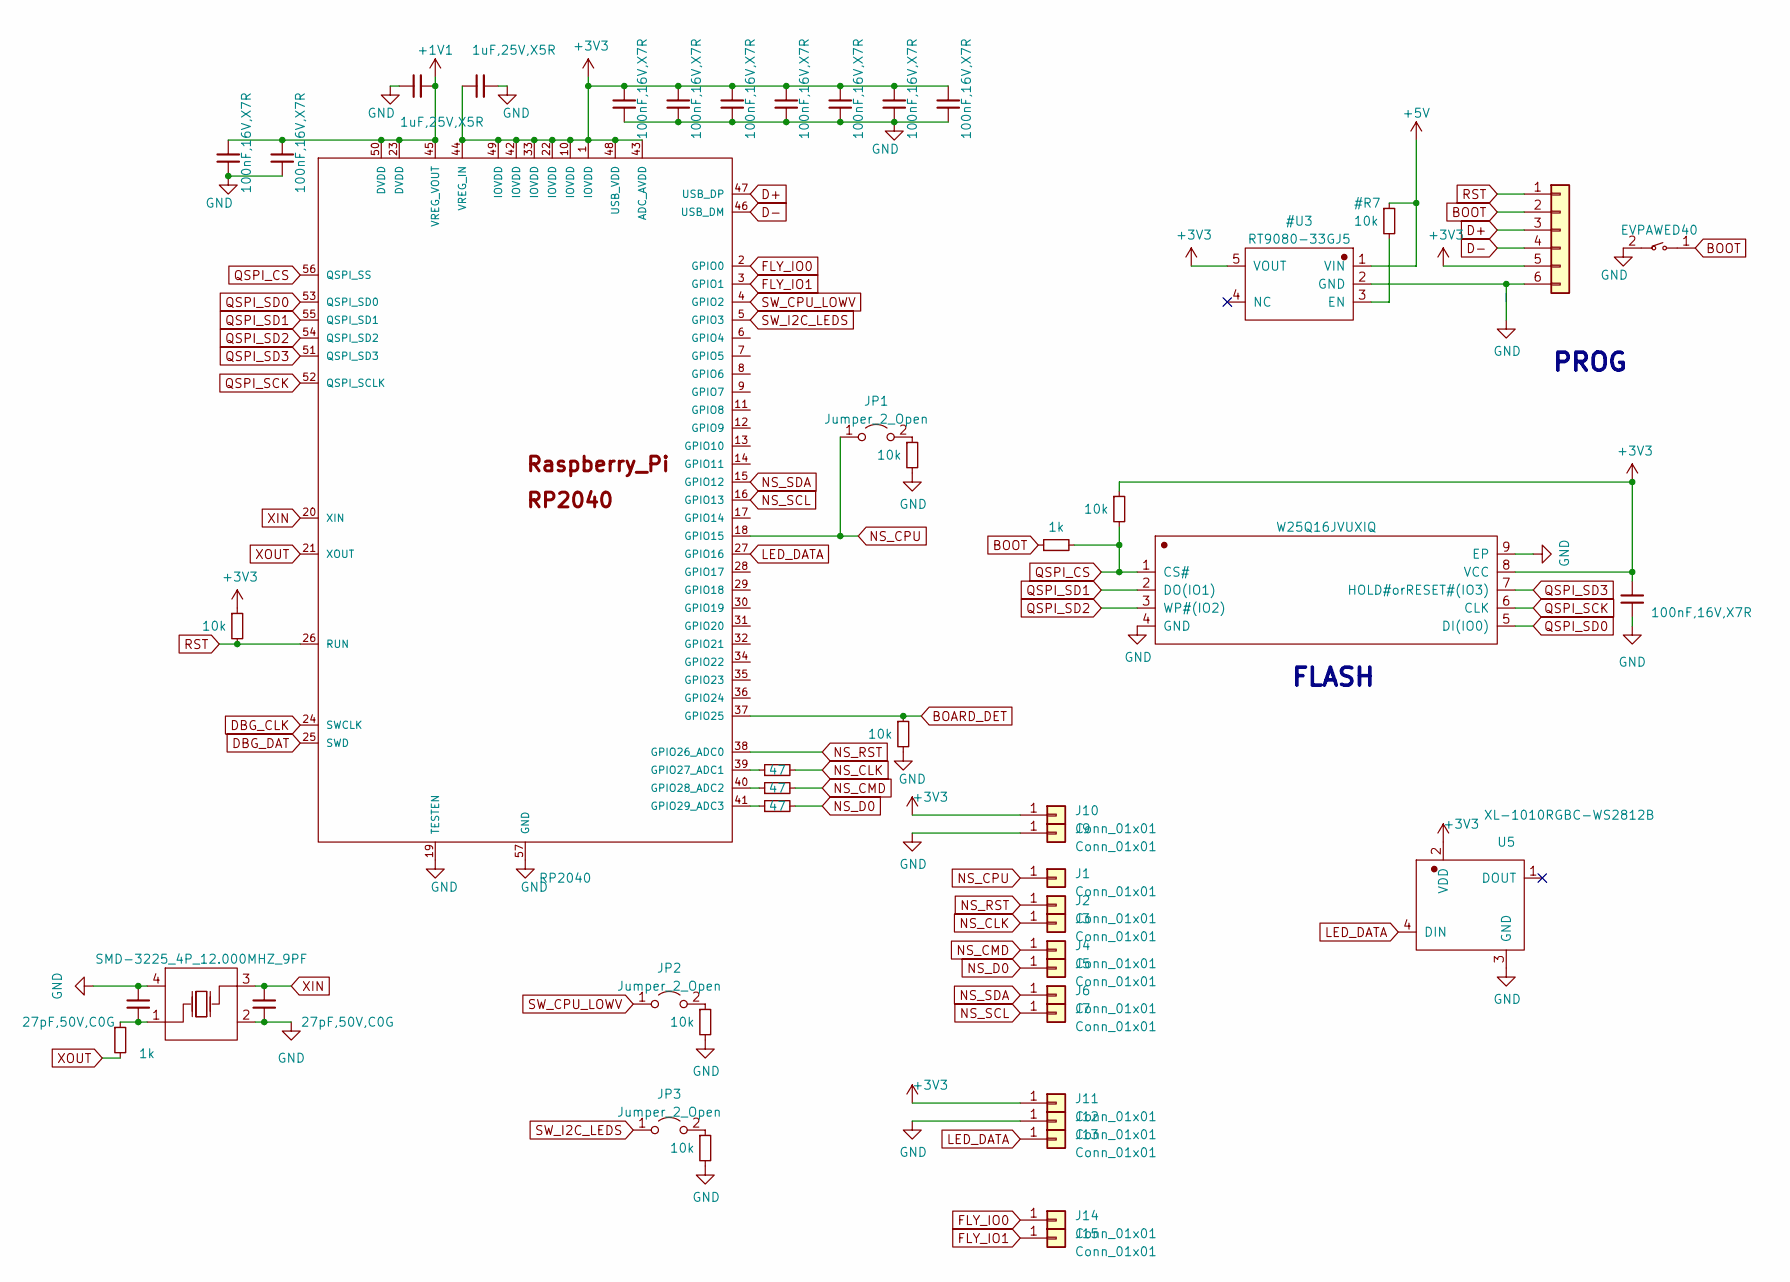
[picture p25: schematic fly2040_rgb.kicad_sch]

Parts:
C1, C3: 27pF,50V,C0G; C_0402_1005Metric; MFGPN 0402CG270J500NT; LCSC C1557
C2, C4, C7, C8, C9, C10, C11, C12, C13, C14: 100nF,16V,X7R; C_0402_1005Metric; MFGPN CL05B104KO5NNNC; LCSC C1525
C5, C6: 1uF,25V,X5R; C_0402_1005Metric; MFGPN CL05A105KA5NQNC; LCSC C52923
J1, J2, J3, J4, J5, J6, J7, J9, J10: Conn_01x01; TH_Pads_1x1_P1.20mml
J8: Conn_01x06; ProgPins_1x06_P1.27mm
J11, J12, J13: Conn_01x01; TH_Pads_1.2x1_P1.20mml
J14, J15: Conn_01x01; Pad_0.2x1mm
JP1, JP2, JP3: Jumper_2_Open; SolderJumper-2_P1.3mm_Open_TrianglePad1.0x1.5mm_Sm
R1, R5: 1k; R_0402_1005Metric; MFGPN 0402WGF1001TCE; LCSC C11702
R2, R3, R4, R6, R7, R12: 10k; R_0402_1005Metric; MFGPN 0402WGF1002TCE; LCSC C25744
R9, R10, R11: 47; R_0402_1005Metric; MFGPN 0402WGF470JTCE; LCSC C25118
SW1: EVPAWED40; KEY-SMD_L3.0-W2.0-LS3.5; LCSC C2858607
U1: RP2040; LQFN-56_L7.0-W7.0-P0.4-EP; LCSC C2040
U2: W25Q16JVUXIQ; USON-8_L3.0-W2.0-P0.50-BL-EP; LCSC C2843335
U5: XL-1010RGBC-WS2812B; LED-SMD_4P-L1.0-W1.0-TL_XL-1010RGBC-WS2812B; LCSC C5349953
X1: SMD-3225_4P_12.000MHZ_9PF; OSC-SMD_4P-L3.2-W2.5-BL; LCSC C362368

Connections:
+1V1: C2.1, C4.1, C5.1, U1.23 (DVDD), U1.45 (VREG_VOUT), U1.50 (DVDD)
BOARD_DET: R3.1, U1.37 (GPIO25)
BOOT: J8.2, R5.1, SW1.1
D+: J8.3, U1.47 (USB_DP)
D-: J8.4, U1.46 (USB_DM)
DBG_CLK: U1.24 (SWCLK)
DBG_DAT: U1.25 (SWD)
FLY_IO0: J14.1, U1.2 (GPIO0)
FLY_IO1: J15.1, U1.3 (GPIO1)
LED_DATA: J13.1, U1.27 (GPIO16), U5.4 (DIN)
NS_CLK: J3.1, R9.2
NS_CMD: J4.1, R10.2
NS_CPU: J1.1, JP1.1 (A), U1.18 (GPIO15)
NS_D0: J5.1, R11.2
NS_RST: J2.1, U1.38 (GPIO26_ADC0)
NS_SCL: J7.1, U1.16 (GPIO13)
NS_SDA: J6.1, U1.15 (GPIO12)
unnamed: JP1.2 (B), R12.1
unnamed: JP2.2 (B), R4.1
unnamed: JP3.2 (B), R7.1
unnamed: R9.1, U1.39 (GPIO27_ADC1)
unnamed: R10.1, U1.40 (GPIO28_ADC2)
unnamed: R11.1, U1.41 (GPIO29_ADC3)
unnamed: C1.2, R1.1, X1.1 (OSC1)
QSPI_CS: R5.2, R6.2, U1.56 (QSPI_SS), U2.1 (CS#)
QSPI_SCK: U1.52 (QSPI_SCLK), U2.6 (CLK)
QSPI_SD0: U1.53 (QSPI_SD0), U2.5 (DI(IO0))
QSPI_SD1: U1.55 (QSPI_SD1), U2.2 (DO(IO1))
QSPI_SD2: U1.54 (QSPI_SD2), U2.3 (WP#(IO2))
QSPI_SD3: U1.51 (QSPI_SD3), U2.7 (HOLD#orRESET#(IO3))
RST: J8.1, R2.2, U1.26 (RUN)
SW_CPU_LOWV: JP2.1 (A), U1.4 (GPIO2)
SW_I2C_LEDS: JP3.1 (A), U1.5 (GPIO3)
XIN: C3.1, U1.20 (XIN), X1.3 (OSC2)
XOUT: R1.2, U1.21 (XOUT)

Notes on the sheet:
PROG
FLASH

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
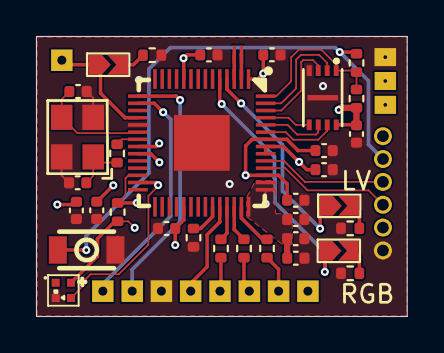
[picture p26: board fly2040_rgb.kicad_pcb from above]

Board: 4 copper layers, 20.6 x 15.6 mm, 48 parts (0 on the bottom side), 35 nets.

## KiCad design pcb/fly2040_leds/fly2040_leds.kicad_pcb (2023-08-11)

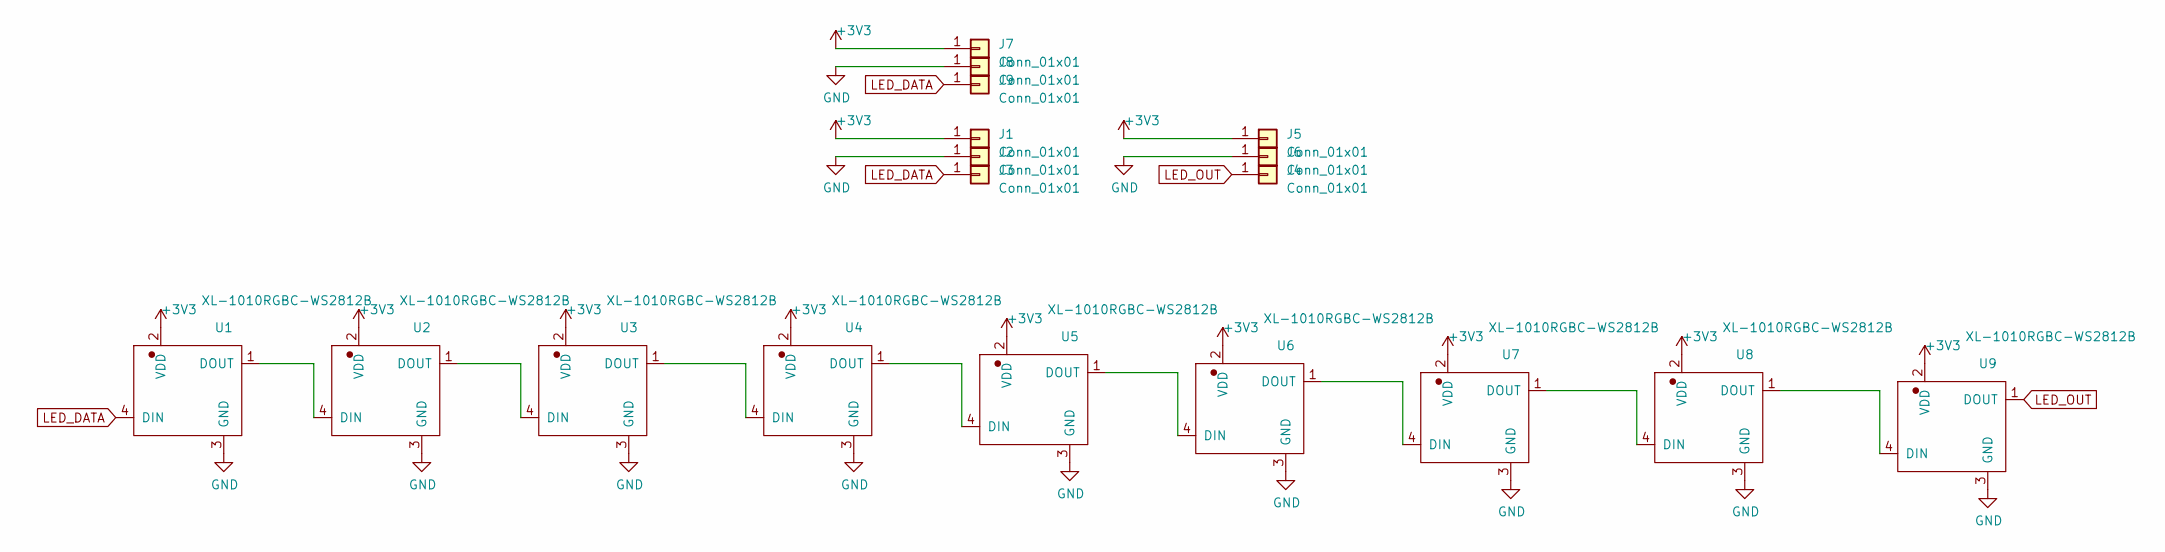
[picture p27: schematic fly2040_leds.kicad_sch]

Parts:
J1, J2, J3, J4, J5, J6, J7, J8, J9: Conn_01x01; TH_Pads_1.2x1_P1.20mml
U1, U2, U3, U4, U5, U6, U7, U8, U9: XL-1010RGBC-WS2812B; LED-SMD_4P-L1.0-W1.0-TL_XL-1010RGBC-WS2812B; LCSC C5349953

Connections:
+3V3: J1.1, J5.1, J7.1, U1.2 (VDD), U2.2 (VDD), U3.2 (VDD), U4.2 (VDD), U5.2 (VDD), U6.2 (VDD), U7.2 (VDD), U8.2 (VDD), U9.2 (VDD)
GND: J2.1, J6.1, J8.1, U1.3 (GND), U2.3 (GND), U3.3 (GND), U4.3 (GND), U5.3 (GND), U6.3 (GND), U7.3 (GND), U8.3 (GND), U9.3 (GND)
LED_DATA: J3.1, J9.1, U1.4 (DIN)
LED_OUT: J4.1, U9.1 (DOUT)
unnamed: U1.1 (DOUT), U2.4 (DIN)
unnamed: U2.1 (DOUT), U3.4 (DIN)
unnamed: U3.1 (DOUT), U4.4 (DIN)
unnamed: U4.1 (DOUT), U5.4 (DIN)
unnamed: U5.1 (DOUT), U6.4 (DIN)
unnamed: U6.1 (DOUT), U7.4 (DIN)
unnamed: U7.1 (DOUT), U8.4 (DIN)
unnamed: U8.1 (DOUT), U9.4 (DIN)

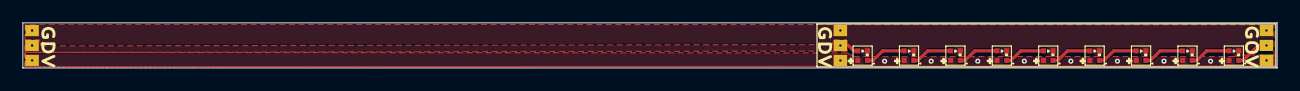
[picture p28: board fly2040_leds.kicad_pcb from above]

Board: 2 copper layers, 111.2 x 4.0 mm, 18 parts (0 on the bottom side), 12 nets.

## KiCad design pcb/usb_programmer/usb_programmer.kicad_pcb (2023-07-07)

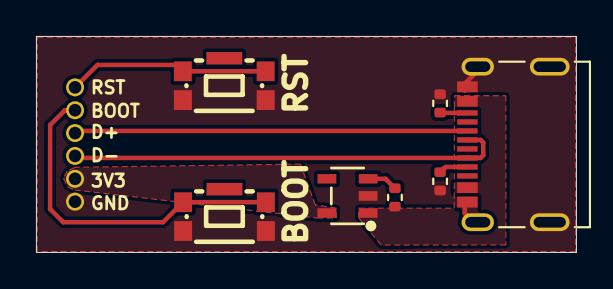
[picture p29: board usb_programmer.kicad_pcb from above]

Board: 2 copper layers, 30.0 x 12.0 mm, 8 parts (0 on the bottom side), 10 nets.

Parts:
J1: TYPE-C-31-M-12; USB_TYPE-C
J2: Conn_01x06; ProgPinsHoles_1x06_P1.27mm
R1: 10k; R_0402_1005Metric
R2, R3: 5.1k; R_0402_1005Metric
SW1, SW3: KMR221GLFS; KEY-SMD_KMR2XXGXXX
U1: RT9080-33GJ5; TSOT-23-5_L2.9-W1.6-P0.95-LS2.8-BL

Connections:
+3V3: J2.5, U1.5 (VOUT)
BOOT: J2.2, SW1.1, SW1.2
D+: J1.A6 (D+), J1.B6 (D+), J2.3
D-: J1.A7 (D-), J1.B7 (D-), J2.4
GND: J1.A1 (GND), J1.A12 (GND), J1.S1 (SHIELD), J2.6, R2.2, R3.2, SW1.3, SW1.4, SW3.3, SW3.4, U1.2 (GND)
unnamed: J1.A5 (CC1), R3.1
unnamed: J1.B5 (CC2), R2.1
unnamed: R1.2, U1.3 (EN)
RST: J2.1, SW3.1, SW3.2
VBUS: J1.A4 (VBUS), J1.A9 (VBUS), R1.1, U1.1 (VIN)

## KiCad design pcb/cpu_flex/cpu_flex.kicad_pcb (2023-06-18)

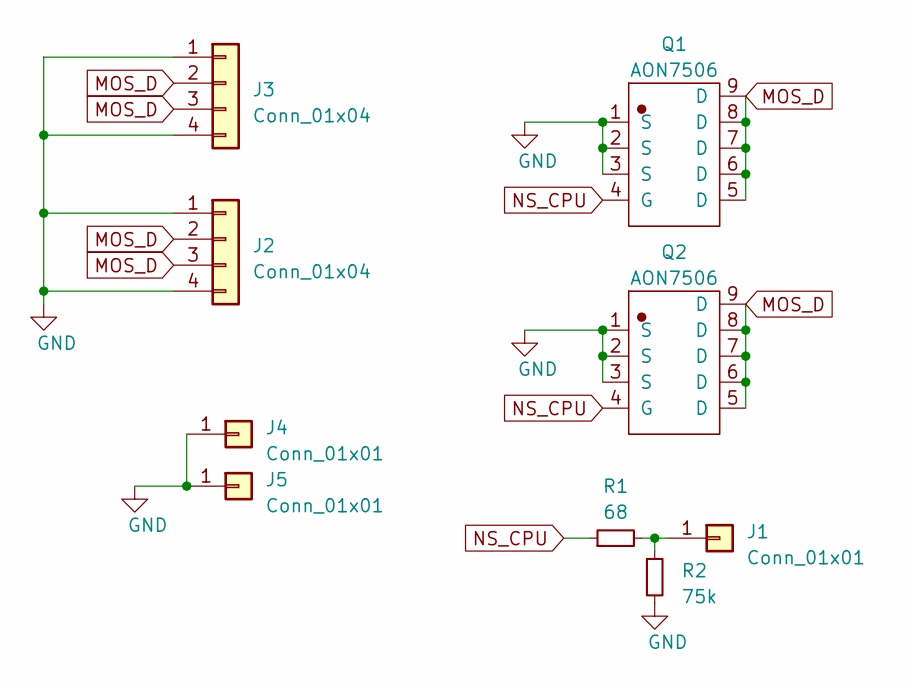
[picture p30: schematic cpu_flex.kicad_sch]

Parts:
J1: Conn_01x01; TH_Pads_1x1_P1.20mml
J2, J3: Conn_01x04; CPU_Pads
J4, J5: Conn_01x01; ThroughPad_2.8x1.5
Q1, Q2: AON7506; DFN-8_L3.0-W3.0-P0.65-BL
R1: 68; R_0603_1608Metric; MFGPN 0603WAF680JT5E; LCSC C27592
R2: 75k; R_0402_1005Metric; MFGPN 0402WGF7502TCE; LCSC C25798

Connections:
GND: J2.1, J2.4, J3.1, J3.4, J4.1, J5.1, Q1.1 (S), Q1.2 (S), Q1.3 (S), Q2.1 (S), Q2.2 (S), Q2.3 (S), R2.2
MOS_D: J2.2, J2.3, J3.2, J3.3, Q1.5 (D), Q1.6 (D), Q1.7 (D), Q1.8 (D), Q1.9 (D), Q2.5 (D), Q2.6 (D), Q2.7 (D), Q2.8 (D), Q2.9 (D)
NS_CPU: Q1.4 (G), Q2.4 (G), R1.1
unnamed: J1.1, R1.2, R2.1

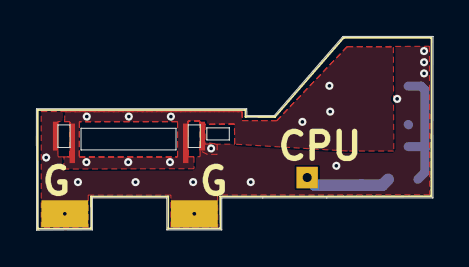
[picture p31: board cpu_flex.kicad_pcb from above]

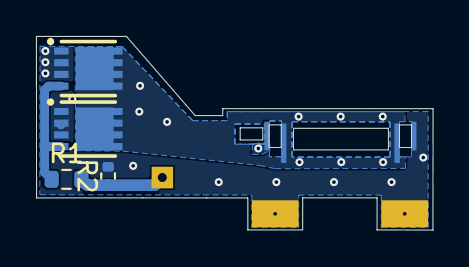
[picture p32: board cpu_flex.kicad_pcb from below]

Board: 2 copper layers, 22.0 x 10.8 mm, 9 parts (5 on the bottom side), 4 nets.

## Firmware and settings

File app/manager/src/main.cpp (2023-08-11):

/*
    Borealis, a Nintendo Switch UI Library
    Copyright (C) 2019-2020  natinusala
    Copyright (C) 2019  p-sam

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
    You should have received a copy of the GNU General Public License
    along with this program.  If not, see <https://www.gnu.org/licenses/>.
*/

#include <stdlib.h>

#include <borealis.hpp>
#include <string>

#include "context.hpp"
#include "buffer.hpp"
#include "main_activity.hpp"
#include "settings_tab.hpp"
#include "pulse_tab.hpp"
#include "cycle_tab.hpp"
#include "rainbow_tab.hpp"
#include "load_tab.hpp"
#include "temperature_tab.hpp"
#include "about_tab.hpp"
#include "debug_tab.hpp"
#include "config_impl.hpp"
#include "file_utils.hpp"

using namespace brls::literals; // for _i18n

int main(int argc, char* argv[])
{
    // Init the app
    brls::Logger::setLogLevel(brls::LogLevel::LOG_DEBUG);

    FileUtils::LogLine("App Launch");

    uint32_t apiVersion;
    bool ipcEnabled = false;

    // Init the app and i18n
    if (!brls::Application::init())
    {
        brls::Logger::error("Unable to init application");
        return EXIT_FAILURE;
    }

    // Check that sys-rgb is running
    if (!sysrgbIpcRunning())
    {
        brls::Logger::error("sys-rgb is not running");
        brls::Application::notify("sys-rgb is not running");
        //brls::Application::crash("sys-rgb does not seem to be running, please check that it is correctly installed and enabled.");
    }
        // Initialize sys-rgb IPC client
    else if (R_FAILED(sysrgbIpcInitialize()) || R_FAILED(sysrgbIpcGetAPIVersion(&apiVersion)))
    {
        brls::Logger::error("Unable to initialize sys-rgb IPC client");
        brls::Application::notify("Unable to initialize sys-rgb IPC client");
        //brls::Application::crash("Could not connect to sys-rgb, please check that it is correctly installed and enabled.");
    }
    else if (SYSRGB_IPC_API_VERSION != apiVersion)
    {
        brls::Logger::error("sys-rgb IPC API version mismatch (expected: %u; actual: %u)", SYSRGB_IPC_API_VERSION,
                            apiVersion);
        brls::Application::notify("sys-rgb IPC API version mismatch");
        //brls::Application::crash("The manager is not compatible with the currently running sysmodule of sys-rgb, please check that you have correctly installed the latest version (reboot?).");
    }
    else
    {
        brls::Logger::debug("IPC connected.");
        ipcEnabled = true;
    }

    brls::Application::createWindow("main/title"_i18n);
    brls::Application::setGlobalQuit(true);

    if (ipcEnabled)
    {
        Result rc = sysrgbIpcGetConfigValues(&ConfigImpl::get());
        if (R_FAILED(rc))
        {
            brls::Logger::info("Get config failed:{}", rc);
        }
    }

    // Register custom views (including tabs, which are views)
    brls::Application::registerXMLView("SettingsTab", SettingsTab::create);
    brls::Application::registerXMLView("PulseTab", PulseTab::create);
    brls::Application::registerXMLView("CycleTab", CycleTab::create);
    brls::Application::registerXMLView("RainbowTab", RainbowTab::create);
    brls::Application::registerXMLView("LoadTab", LoadTab::create);
    brls::Application::registerXMLView("TemperatureTab", TemperatureTab::create);
    brls::Application::registerXMLView("AboutTab", AboutTab::create);
    brls::Application::registerXMLView("DebugTab", DebugTab::create);

    // Add custom values to the style
    brls::getStyle().addMetric("about/padding_top_bottom", 50);
    brls::getStyle().addMetric("about/padding_sides", 75);
    brls::getStyle().addMetric("about/description_margin", 50);

    // Create and push the main activity to the stack
    brls::Application::pushActivity(new MainActivity());

    // Run the app
    while (brls::Application::mainLoop());

    sysrgbIpcExit();

    // Exit
    return EXIT_SUCCESS;
}

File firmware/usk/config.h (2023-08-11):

#include "hardware/flash.h"
#define OFFSET_DIV 10
#define OFFSET_MIN 9200
#define OFFSET_MAX 10300

#define VER_HI 2
#define VER_LO 76

bool is_configured();
void init_config();
bool is_inited();
void erase_config();
void add_boot_record(int offset);
int find_best_record(int * max_weight);
bool fast_check();
int get_weigth(int offset);

bool is_i2c_configured();
void set_i2c_configured();

#define CONFIG_START 0x8000 // change to 0x100000 when compiling in "default mode"
#define CONFIG_IDX(offset) (((offset - OFFSET_MIN) / OFFSET_DIV) + 1)
#define CONFIG_CNT CONFIG_IDX(OFFSET_MAX)
#define OFFSET_CNT (CONFIG_CNT-1)
#define CONFIG_SIZE  (CONFIG_CNT * 256)

#define flash_cfg ((const uint8_t *) (XIP_BASE + CONFIG_START))

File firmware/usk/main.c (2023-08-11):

#include <stdio.h>
#include <stdlib.h>
#include <string.h>

#include "pico/stdlib.h"
#include "hardware/adc.h"
#include "hardware/pio.h"
#include "hardware/clocks.h"
#include "hardware/vreg.h"
#include "hardware/xosc.h"
#include "hardware/watchdog.h"
#include "boot_detect.h"
#include "board_detect.h"
#include "config.h"

#include "misc.h"
#include "glitch.h"
#include "fuses.h"
#include "pio_upload.h"
#include "pins.h"
#include "leds.h"

extern bool was_self_reset;

bool write_payload();

// overclock to 300 MHz
void init_system() {
    vreg_set_voltage(VREG_VOLTAGE_1_30);
	set_sys_clock_khz(300000, true);
}

// filled within "fast check" on eMMC init
extern uint8_t cid_buf[17];

void rewrite_payload()
{
    put_pixel(PIX_whi);
    write_payload();
    put_pixel(PIX_blu);
    // used to automatically rewrite payload when eMMC/console changes
    init_config(cid_buf + 1);
}

bool safe_test_voltage(int pin, float target, float range)
{
    gpio_enable_input_output(pin);
    adc_gpio_init(pin);
    adc_select_input(pin - 26);
    uint16_t result = adc_read();
    gpio_disable_input_output(pin);
    float voltage = result * 3.3f / (1 << 12);
    return voltage >= (target - range) && voltage <= (target + range);
}

// test all ADC pins
void self_test()
{
    absolute_time_t tio_time = make_timeout_time_ms(2500);
    adc_init();
    bool rst_ok = false, cmd_ok = false, d0_ok = false, clk_ok = false;
    while (!time_reached(tio_time)) {
        if (!rst_ok)
            rst_ok |= safe_test_voltage(PIN_RST, 1.8f, 0.2f);
        if (!cmd_ok)
            cmd_ok |= safe_test_voltage(PIN_CMD, 1.8f, 0.2f);
        if (!d0_ok)
            d0_ok |= safe_test_voltage(PIN_DAT, 1.8f, 0.2f);
        if (rst_ok && cmd_ok && d0_ok)
            break;
    }
    if(!rst_ok)
    {
        finish_with_code(0, 2);
    }
    if(!cmd_ok)
    {
        finish_with_code(1, 2);
    }
    if(!d0_ok)
    {
        finish_with_code(2, 2);
    }
}

int main()
{
    // stop watchdog
    *(uint32_t*)(0x40058000 + 0x3000) = (1 << 30);
    // init reset, mosfet and LED
    detect_board();
    // clocks & voltage
	init_system();
    // fuses counter
    init_fuses();
    // LED & glitch & emmc PIO
    upload_pio();

    // Setup led/i2c state & enable led pio/power.
    init_pixels();

    // check if this is the very first start
    if (watchdog_caused_reboot() && boot_try == 0)
	{
		finish_with_code(1, 1);
	}
    // is chip reset required
    bool force_button = detect_by_pull_up(1, 0);
    // start LED
    put_pixel(PIX_blu);
    // test pins
    self_test();
    // wait till the CPU has proper power & started reading the eMMC
    wait_for_boot(2500);
    // ensure the BCT has not been overwritten by system update
    bool force_check = fast_check();
    was_self_reset = force_button || !is_configured(cid_buf + 1);
    // perform payload rewrite if required
    if (!force_check || was_self_reset) {
        rewrite_payload();
    }
    // setup the glitch trigger for Mariko
    if (mariko) {
        pio1->instr_mem[gtrig_pio_offset + 4] = pio_encode_nop();
        pio1->instr_mem[gtrig_pio_offset + 5] = pio_encode_nop();
    }
    // start from some default width
    int width = 150;
    bool glitched = false;
    int offset = 0;
    for (int full_try = 0; full_try < 2; full_try++) {
        // try saved records
        for (int y = 0; (y < 2) && !glitched; y++) {
            int max_weight = -1;
            while (1) {
                offset = find_best_record(&max_weight);
                if (offset == -1)
                    break;
                // try glitch
                glitched = glitch_try_offset(offset, &width, 3);
                if (glitched)
                    break;
            }
        }
        if (!glitched) {
            for(int z = 0; (z < 2) && !glitched; z++) {
                prepare_random_array();
                for(int y = 0; y < OFFSET_CNT; y++)
                {
                    offset = offsets_array[y];
                    glitched = glitch_try_offset(offset, &width, 4);
                    if (glitched)
                        break;
                }
            }
        }
        if (glitched) {
            if ((count_fuses() & 1) != boot_slot)
            {
                // finish update / rollback
                burn_fuse();
            }
            add_boot_record(offset);
            finish_with_code(0, 1);
        }
        if (full_try == 0) {
            rewrite_payload();
        }
    }
    // attempts limit
    finish_with_code(7, 3);
}

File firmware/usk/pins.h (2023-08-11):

#define PIN_GLI_WS 15
#define PIN_GLI_XIAO 6
#define PIN_GLI_PICO 21
#define PIN_GLI_ITSY 24

#define PIN_LED_WS 16
#define PIN_LED_ITSY 17
#define PIN_LED_XIAO 12
#define PIN_LED_PICO 25

#define PIN_LED_PWR_XIAO 11
#define PIN_LED_RED_XIAO 17
#define PIN_LED_GRN_XIAO 16
#define PIN_LED_BLU_XIAO 25

#define PIN_SDA_WS 12
#define PIN_SDA_XIAO 3
#define PIN_SDA_PICO 19
#define PIN_SDA_ITSY 18
#define PIN_SDA_SQC 18

#define PIN_SCL_WS 13
#define PIN_SCL_XIAO 4
#define PIN_SCL_PICO 20
#define PIN_SCL_ITSY 19
#define PIN_SCL_SQC 19

#define PIN_LED_PWR_ITSY 16

#define PIN_RGB_MODE_WS 25

// fly2040 solder jumpers
#define PIN_I2C_MODE_LV 2
#define PIN_I2C_MODE_LEDS 3

#define PIN_DAT 29
#define PIN_CMD 28
#define PIN_CLK 27
#define PIN_RST 26

#define PIN_TEMP_PICO 29

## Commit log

2023-05-22 Added more outputs. Improved board layout for panel. Added panel files
    [fly2040-CuBottom.gbr, fly2040-CuIn1.gbr, fly2040-CuIn2.gbr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]
2023-05-24 Add minimal board design.
    [fly2040_min-CuBottom.gbr, fly2040_min-CuIn1.gbr, fly2040_min-CuIn2.gbr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]
2023-05-24 Add Images.
    [fly2040_min.kicad_pcb]
2023-05-27 Added tiny double sided (ds) board.
    [fly2040.kicad_pcb, fly2040.kicad_sch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]
2023-05-29 Fix gitignore and push production files
    [BOM-fly2040.csv, BOM-fly2040_ds.csv, BOM-fly2040_min.csv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]
2023-06-02 Updated main board with bus isolation ICs
    [BOM-fly2040.csv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]
2023-06-03 Minor fixes to min board to prep for production run.
    [BOM-fly2040.csv, BOM-fly2040_min.csv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]
2023-06-18 Add WIP CPU flex design.
    [bom.csv, cpu_flex.kicad_pcb, cpu_flex.kicad_sch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]
2023-07-07 Add pogo-pins programmer board
    [2-84952-4.step, 436333045822_Download_STP_436333045822_rev1.stp, 528080470.stp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]
2023-08-11 Added new board, leds, apps, firmware
    [BOM-fly2040.csv, BOM-fly2040_ds.csv, BOM-fly2040_leds.csv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]

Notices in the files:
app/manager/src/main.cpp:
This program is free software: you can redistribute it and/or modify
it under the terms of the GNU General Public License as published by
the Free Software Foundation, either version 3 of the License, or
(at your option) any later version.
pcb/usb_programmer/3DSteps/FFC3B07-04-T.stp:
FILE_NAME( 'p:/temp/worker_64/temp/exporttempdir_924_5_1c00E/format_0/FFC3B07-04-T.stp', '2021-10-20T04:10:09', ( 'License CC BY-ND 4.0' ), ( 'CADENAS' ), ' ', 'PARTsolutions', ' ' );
